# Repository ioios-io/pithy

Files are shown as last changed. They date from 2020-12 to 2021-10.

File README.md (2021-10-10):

# The Pithy Range @ [ioios.io](https://ioios.io/products/pithy)

     
---
## The quickest way to add extra control to your Smart Home
[](https://ioios.io) The Pithy range was conceived to fill the gap in the smart home arena so as to provide simple and intuitive phyiscal controls for adjusting volume, dimming lights, changing heating settings or whatever you chose!

The Open-Source devices are centered around a Wemos D1 Mini and they all feature a rotary encoder, a side switch and a temperature/huimdity sensor. Additionally, the Pixel model has a 16 LED NeoPixel ring for a display whilst the Screen model has... you guessed it, a screen.

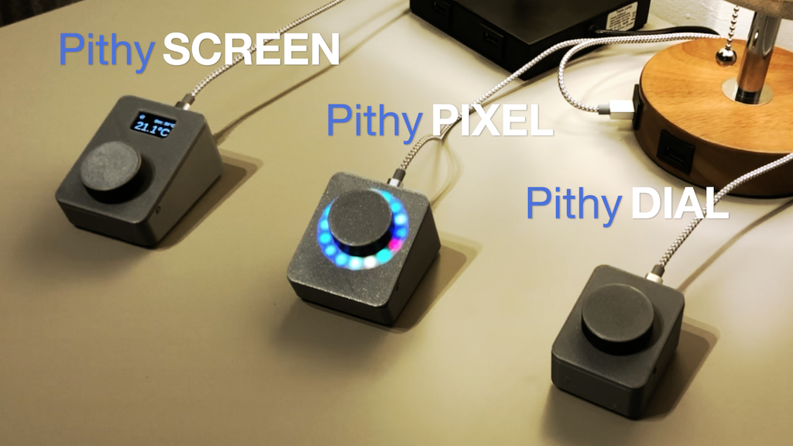
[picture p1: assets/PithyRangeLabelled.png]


## Pins
When writing esphome configuration for the Pithy range you will need to use the following pins for the latest board versions.

| Function | D1 Mini PIN |
|---|---|
| I2C Clock | D3 |
| I2C Data | D4 |
| Side Button | TX |
| PIR Sensor 1* | D1 |
| PIR Sensor 2* | D2 |
| Rotary Encoder A | D5 |
| Rotary Encoder B | D6 |
| Rotary Switch | D7 |
| NeoPixels* | RX |
| DHT22 Temp* | D0 |

(* Denotes items that may not be installed on all versions of a given model)

## The Files
In this repo you will find both the PCB files and the cases. In both sections the files are provided in multiple formats and include the official designs and also community contributions.
##### The Design Process
The PCBs were designed in Autodesk Eagle (using a custom made component library with 100% 3D renders). They were then imported/linked to Autodesk Fusion 360 where the cases were designed to perfectly fit and compliemnt the PCBs.
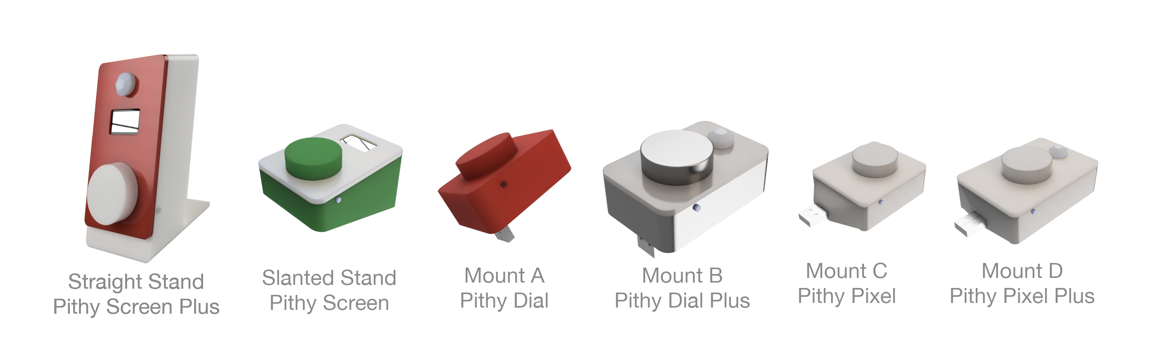
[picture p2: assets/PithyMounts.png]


## Contributions
It is Open-Source for a reason! If you would like to contribute your modifications or creations to the project, please follow these steps:
1. Fork this repo
2. Create a new, descriptively-named directory within the appropriate 'community' directory
3. Create a README.md file to briefly explain your ideas and if required, instructions for use/assembly
4. Don't forget to credit yourself and anyone else involved!
4. Create a pull request

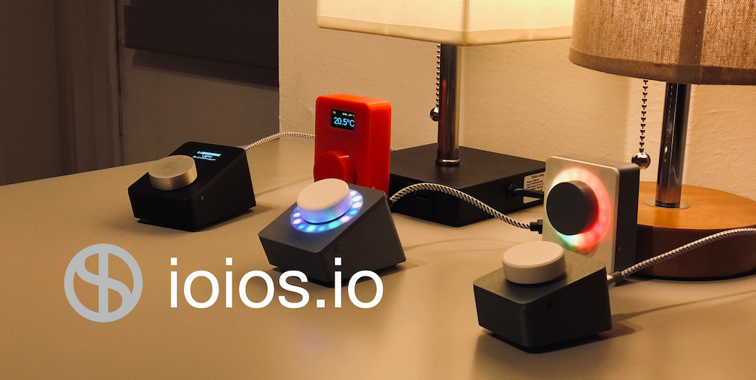
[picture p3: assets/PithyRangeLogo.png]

___

```
John Lumley
15th March 2021
```

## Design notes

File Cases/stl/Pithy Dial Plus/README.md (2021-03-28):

## Pithy Dial Plus
STL files for the Pithy Dial Plus models.
___

#### Mounting Options
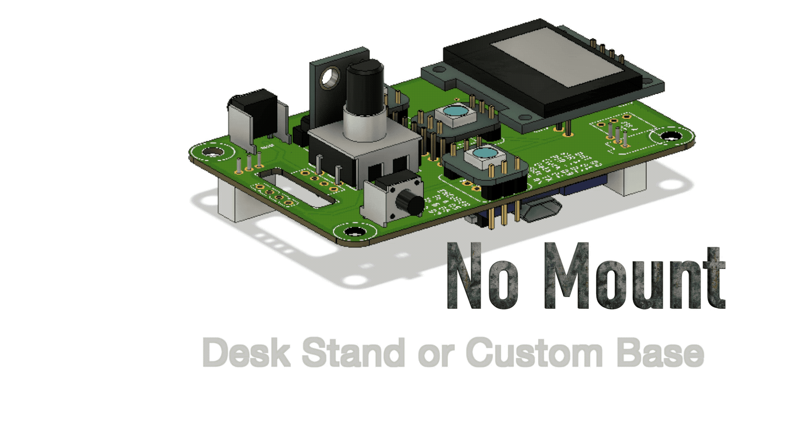
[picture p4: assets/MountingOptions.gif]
Mounting Options Animation


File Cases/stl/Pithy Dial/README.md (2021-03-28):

## Pithy Dial
STL files for the Pithy Dial models.
___

#### Mounting Options
Mounting Options Animation

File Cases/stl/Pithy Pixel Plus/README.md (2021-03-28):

## Pithy Pixel Plus
STL files for the Pithy Pixel Plus models.
___

#### Mounting Options
Mounting Options Animation

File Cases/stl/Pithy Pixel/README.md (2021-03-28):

## Pithy Pixel
STL files for the Pithy Pixel models.
___

#### Mounting Options
Mounting Options Animation

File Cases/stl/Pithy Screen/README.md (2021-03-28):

## Pithy Screen
STL files for the Pithy Screen models.
___

#### Mounting Options
Mounting Options Animation

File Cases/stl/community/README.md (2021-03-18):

# Community
## Entirely new configurations of Pithy PCBs
#### Ideally with full range of printable cases

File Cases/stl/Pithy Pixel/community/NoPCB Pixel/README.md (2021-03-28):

## Wemos D1 mini

I've added a case to use a standalone Wemos D1 mini without the PCB.

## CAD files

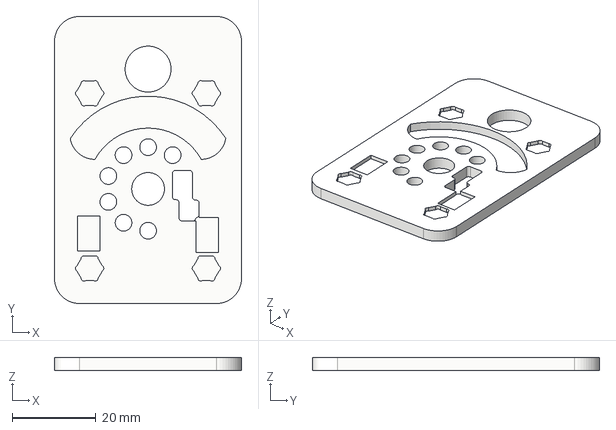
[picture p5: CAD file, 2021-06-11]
Cases/step/Pithy Dial Plus/Pithy Dial Plus Faceplate.step
44.8 x 68.7 x 3.00 mm

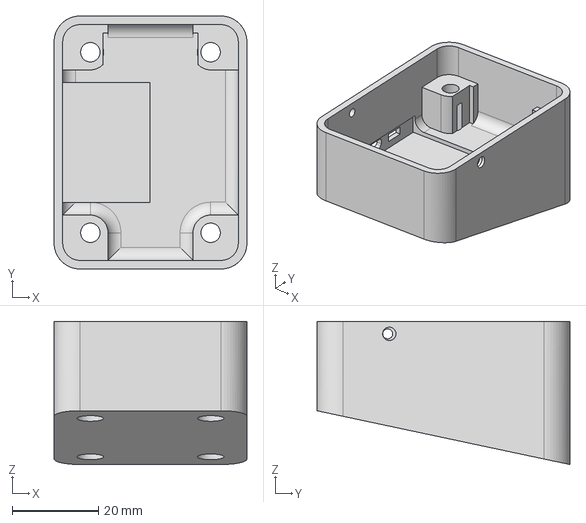
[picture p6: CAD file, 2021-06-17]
Cases/step/Pithy Dial/Pithy Dial Slanted Stand.step
44.8 x 58.7 x 33.2 mm

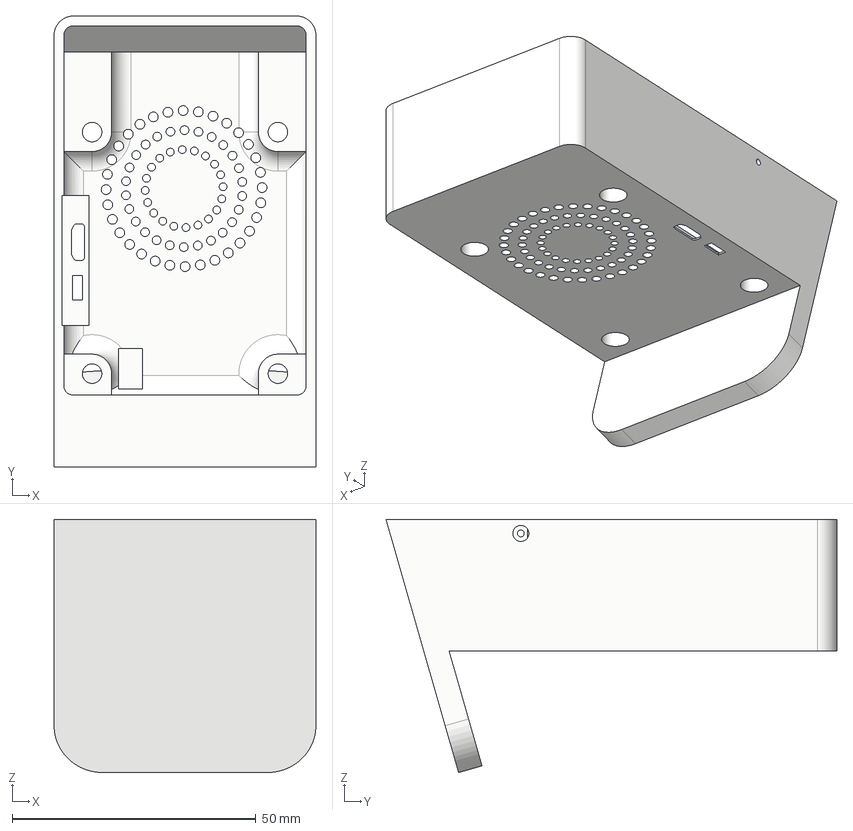
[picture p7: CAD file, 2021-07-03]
Cases/step/Pithy Pixel Plus/Pithy Pixel Plus Straight Stand.step
53.7 x 92.5 x 51.9 mm

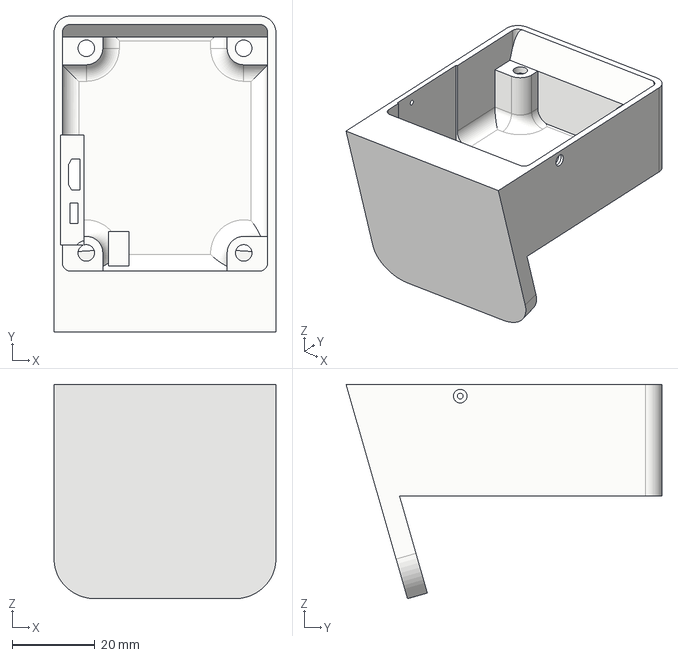
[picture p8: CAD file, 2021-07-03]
Cases/step/Pithy Pixel/Pithy Pixel Straight Stand.step
53.7 x 76.5 x 51.9 mm

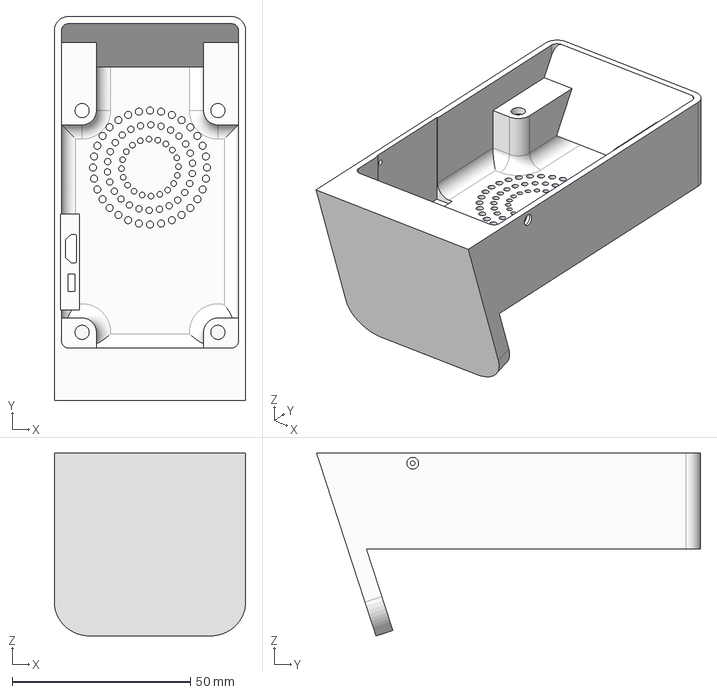
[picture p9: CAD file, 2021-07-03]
Cases/step/Pithy Screen Plus/Pithy Screen Plus Straight Stand.step
53.7 x 107.8 x 51.4 mm

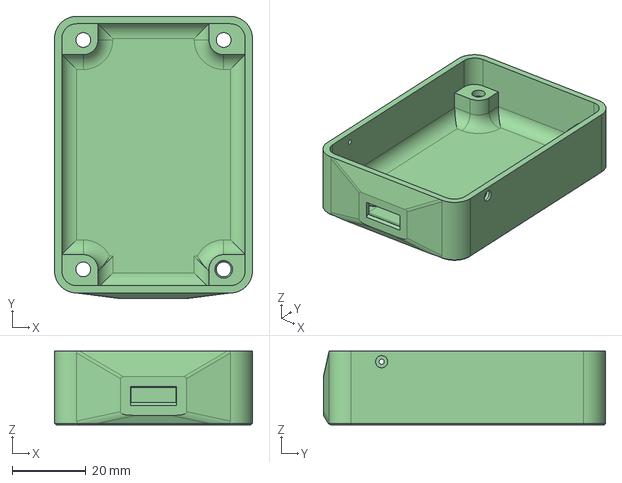
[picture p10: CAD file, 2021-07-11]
Cases/step/Pithy Screen/Pithy Screen Mount D.step
53.7 x 76.6 x 20.0 mm

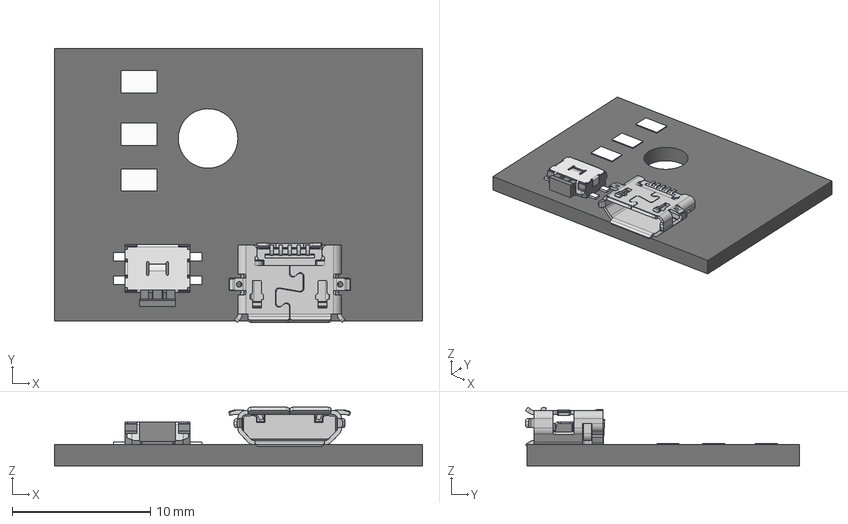
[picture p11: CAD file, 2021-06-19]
Cases/step/USB Micro Adapter.step
26.6 x 19.8 x 4.23 mm
zx62r-b-5p_30_
frame
pins
pins (1)
pins (2)
pins (3)
stem
cover
PCB

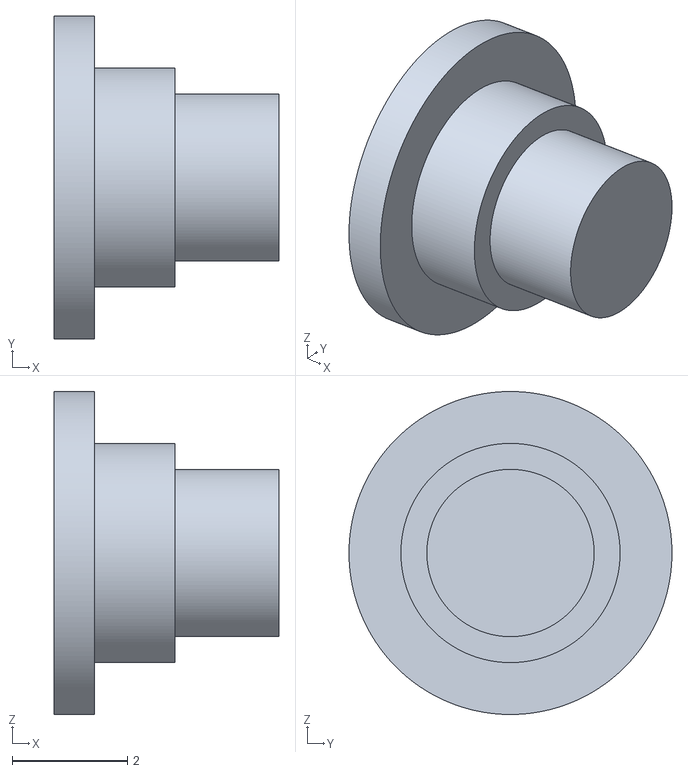
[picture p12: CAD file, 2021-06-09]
Cases/stl/Pithy Dial Plus/Pithy Secret Switch.stl
3.90 x 5.60 x 5.60

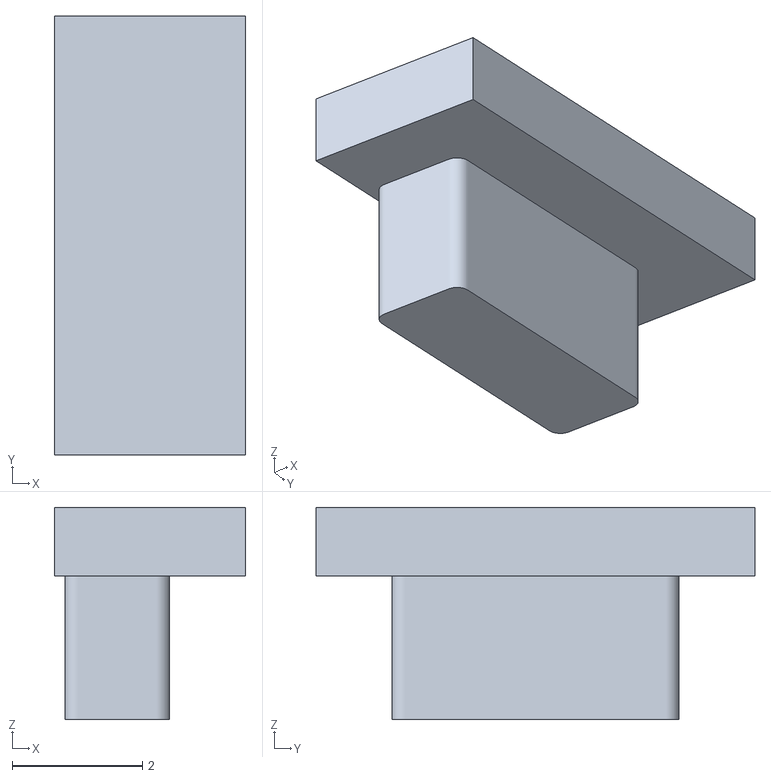
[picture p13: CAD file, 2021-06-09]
Cases/stl/Pithy Pixel Plus/Pithy Reset Switch.stl
2.93 x 6.73 x 3.25

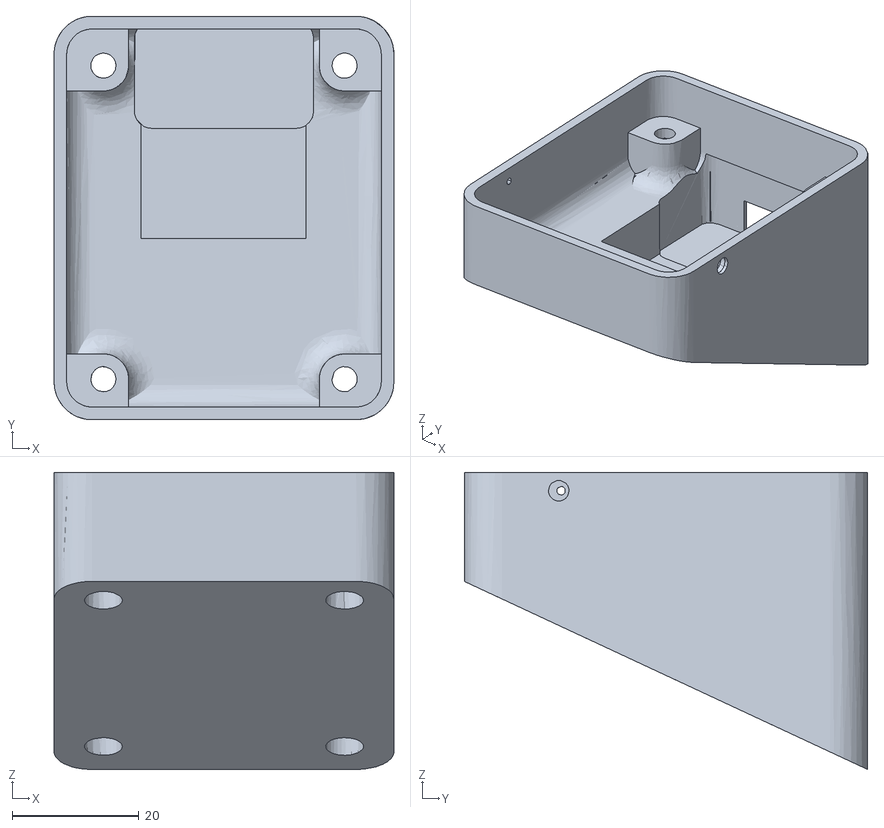
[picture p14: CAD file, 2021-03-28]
Cases/stl/Pithy Pixel/community/NoPCB Pixel/NoPCB Pixel.stl
53.7 x 63.8 x 46.9

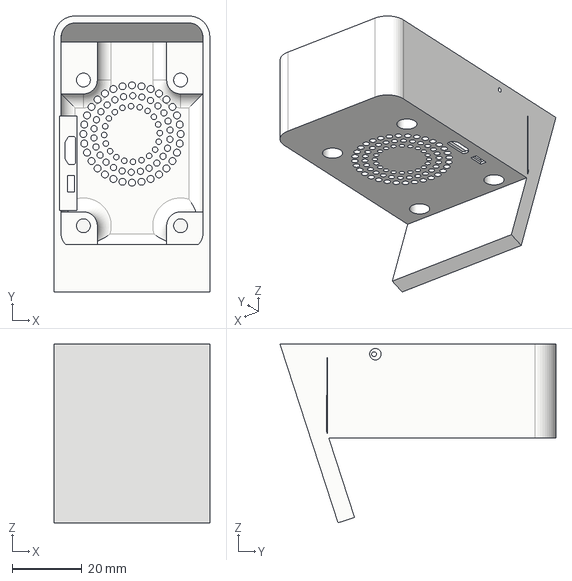
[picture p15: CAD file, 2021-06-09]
Cases/step/Pithy Dial Plus/Pithy Dial Plus Straight Stand.step
44.8 x 79.4 x 51.4 mm

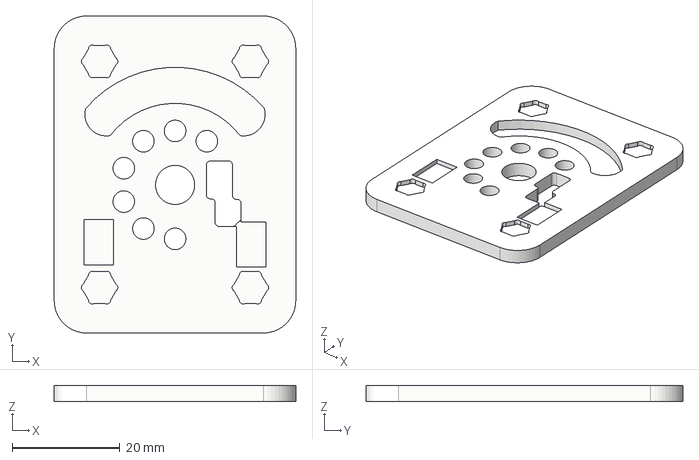
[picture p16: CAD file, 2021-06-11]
Cases/step/Pithy Dial/Pithy Dial Faceplate.step
44.8 x 58.7 x 3.00 mm

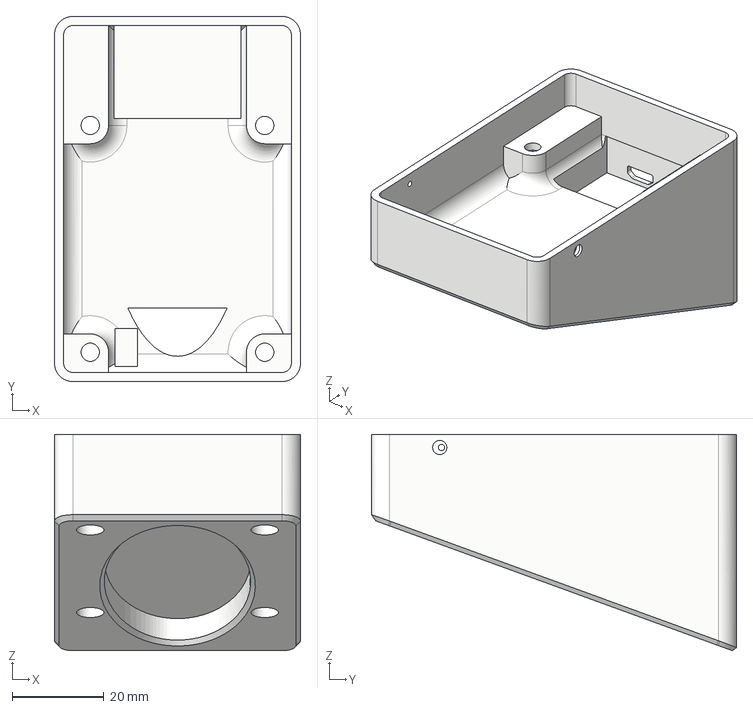
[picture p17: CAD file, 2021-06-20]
Cases/step/Pithy Pixel Plus/Pithy Pixel Plus Slanted Stand.step
53.7 x 79.8 x 47.2 mm

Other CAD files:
Cases/step/Pithy Pixel/Pithy Pixel Slanted Stand.step
Cases/step/Pithy Dial Multi Mount.step
Cases/step/Pithy Dial Plus/Pithy Dial Plus Mount A.step
Cases/step/Pithy Dial Plus/Pithy Dial Plus Mount B.step
Cases/step/Pithy Dial Plus/Pithy Dial Plus Mount C.step
Cases/step/Pithy Dial Plus/Pithy Dial Plus Mount D.step
Cases/step/Pithy Dial/Pithy Dial Mount A.step
Cases/step/Pithy Dial/Pithy Dial Mount B.step
Cases/step/Pithy Dial/Pithy Dial Mount C.step
Cases/step/Pithy Dial/Pithy Dial Mount D.step
Cases/step/Pithy PIxel Multi Mount.step
Cases/step/Pithy Pixel Plus/Pithy Pixel Plus Faceplate.step
Cases/step/Pithy Pixel Plus/Pithy Pixel Plus Mount A.step
Cases/step/Pithy Pixel Plus/Pithy Pixel Plus Mount B.step
Cases/step/Pithy Pixel Plus/Pithy Pixel Plus Mount C.step
Cases/step/Pithy Pixel Plus/Pithy Pixel Plus Mount D.step
Cases/step/Pithy Pixel/Pithy Pixel Faceplate.step
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

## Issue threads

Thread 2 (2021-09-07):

Pithy screen plus stuck on loading screen

Adam-North, 2021-09-07:
just flashed the d1 mini and it boots up correctly when plugged in directly to the d1 mini but not when plugged in through the power board. The loading bar just scrolls across the screen.

Adam-North, 2021-09-07:
pir sensor was preventing bootup. resoldered it and it works now.

Closed 2021-09-07.

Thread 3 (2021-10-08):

Pin numbers & PDF of the wiring diagram

mikeyyuen, 2021-10-08:
Hello, would you mind putting a specification for what the different pins people should use in the esphome files?

e.g. https://github.com/ioios-io/demos/blob/main/Home%20Assistant%20with%20ESPHome/4.%20All-In-One/All-In-One-ESPHome-PithyScreen.yaml

I've noticed some of the examples in the demo folder use D1/2 for i2c and others use D3/4, I wondered if it might be different for different models, but I have a pith screen plus and couldn't get most of the demo's to work out of the box.

ioios-io, 2021-10-10:
Hi Mike,
Yes, I'll add that to the to-do list but can't promise when it'll hit Github. I appreciate it is useful information (the pins are on the front of the PCB but pre-built units will never see those).

In the meantime, here is a list of the pin mappings at least.

D0: DHT
D1: PIR 1
D2: PIR 2
D3: I2C Clock
D4: I2C Data
D5: Encoder 1
D6: Encoder 2
D7: Encoder Switch
TX: Side Switch
RX: Neopixels

Thanks,
John

mikeyyuen, 2021-10-10:
Thank you, and your welcome for the pr! Glad I could help a little bit!

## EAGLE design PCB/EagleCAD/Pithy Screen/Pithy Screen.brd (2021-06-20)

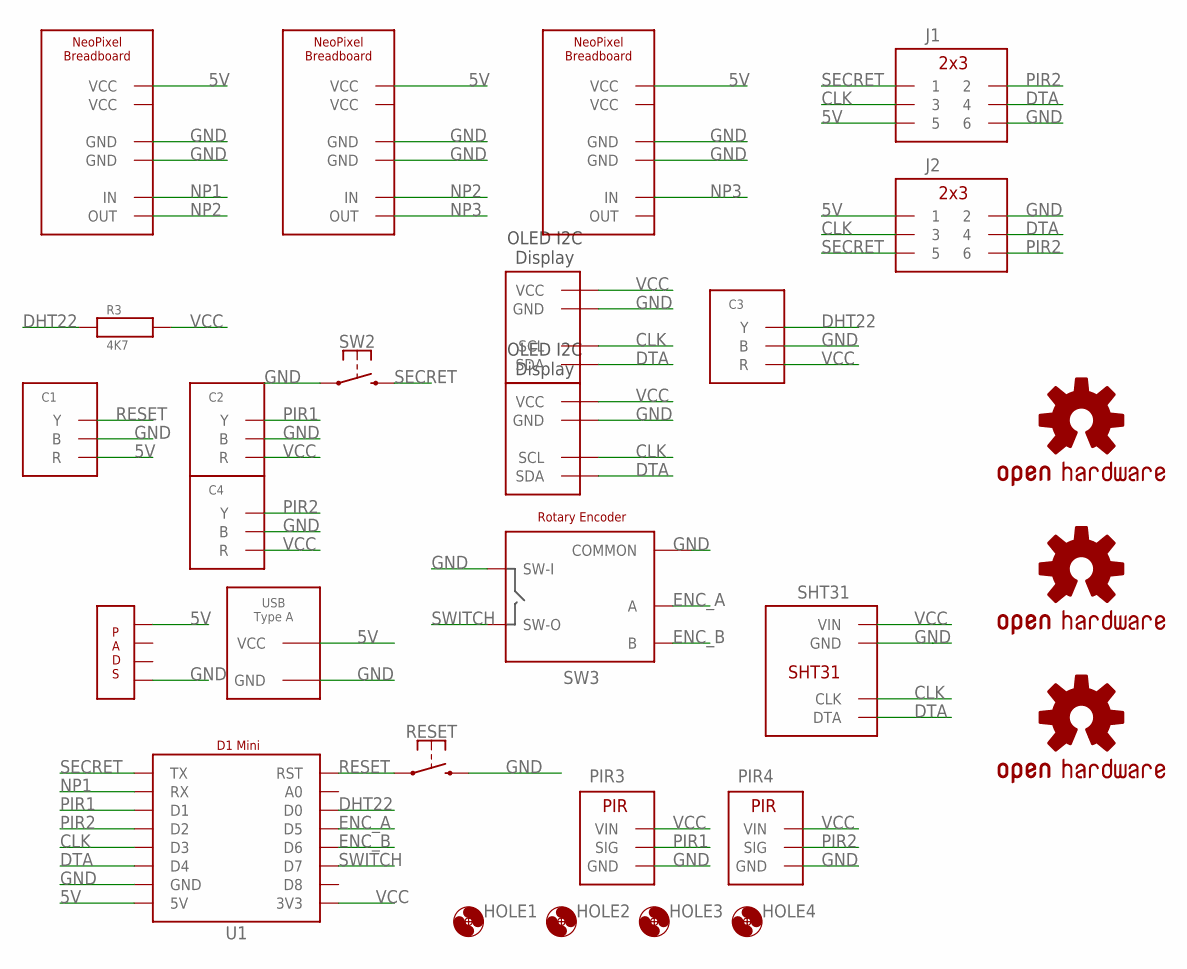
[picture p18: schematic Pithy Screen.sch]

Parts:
C1, C2, C3, C4: JST_2MM_3PIN
HOLE1, HOLE2, HOLE3, HOLE4: HOLE_3.2
J1, J2: DIL_2X03FEMALE; 2X3-RAF
LOGO1: OSHW-LOGOL; OSHW-LOGO-L
LOGO2: OSHW-LOGOM; OSHW-LOGO-M
LOGO3: OSHW-LOGOS; OSHW-LOGO-S
NP1, NP2, NP3: NEOPIXEL_BREADBOARD
PIR3, PIR4: PIR45DEG; PIR_45DEG
R3: 4K7; 1/4W_RESISTOR
RESET: SPDT_MOMENTARY; SPDT_RIGHT_ANGLE
SHT31: SHT31RIGHT_ANGLED; SHT31_RIGHT_ANGLE
SW2: SPDT_MOMENTARY; SPDT_RIGHT_ANGLE
SW3: ENCODER; ROTARY_ENCODER
U1: D1_MINI
U2, U3: OLED_I2C_0.9"VCC_LEFT; OLED_I2C_0.9"_ALT
U$1: USB_TYPE_A; USB_TYPE_A_BACKWARDS
U$2: PADS_4

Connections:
5V: C1.RED (R), J1.5, J2.1, NP1.VCC, NP2.VCC, NP3.VCC, U1.5V, U$1.VCC, U$2.P$4
CLK: J1.3, J2.3, SHT31.CLK, U1.D3, U2.SCL, U3.SCL
DHT22: C3.YELLOW (Y), R3.P$1, U1.D0
DTA: J1.4, J2.4, SHT31.DTA, U1.D4, U2.SDA, U3.SDA
ENC_A: SW3.A, U1.D5
ENC_B: SW3.B, U1.D6
GND: C1.BLACK (B), C2.BLACK (B), C3.BLACK (B), C4.BLACK (B), J1.6, J2.2, NP1.GND, NP1.GND@2 (GND), NP2.GND, NP2.GND@2 (GND), NP3.GND, NP3.GND@2 (GND), PIR3.GND, PIR4.GND, RESET.2 (3), SHT31.GND, SW2.1, SW3.C (COMMON), SW3.SW+ (SW-I), U1.GND, U2.GND, U3.GND, U$1.GND, U$2.P$1
NP1: NP1.IN, U1.RX
NP2: NP1.OUT, NP2.IN
NP3: NP2.OUT, NP3.IN
PIR1: C2.YELLOW (Y), PIR3.SIG, U1.D1
PIR2: C4.YELLOW (Y), J1.2, J2.6, PIR4.SIG, U1.D2
RESET: C1.YELLOW (Y), RESET.1, U1.RST
SECRET: J1.1, J2.5, SW2.2 (3), U1.TX
SWITCH: SW3.SW- (SW-O), U1.D7
VCC: C2.RED (R), C3.RED (R), C4.RED (R), PIR3.VCC (VIN), PIR4.VCC (VIN), R3.P$2, SHT31.VIN, U1.3V3, U2.VCC, U3.VCC

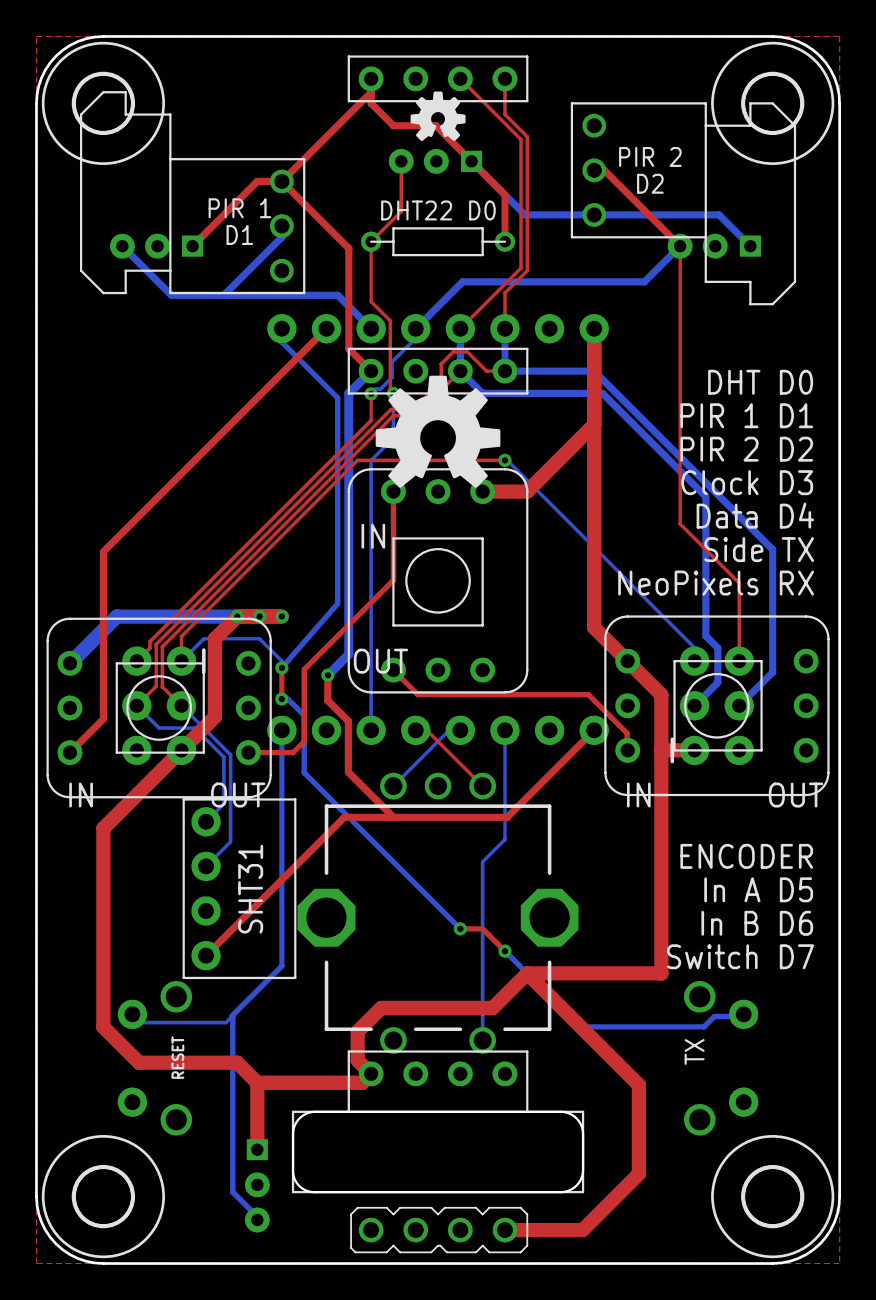
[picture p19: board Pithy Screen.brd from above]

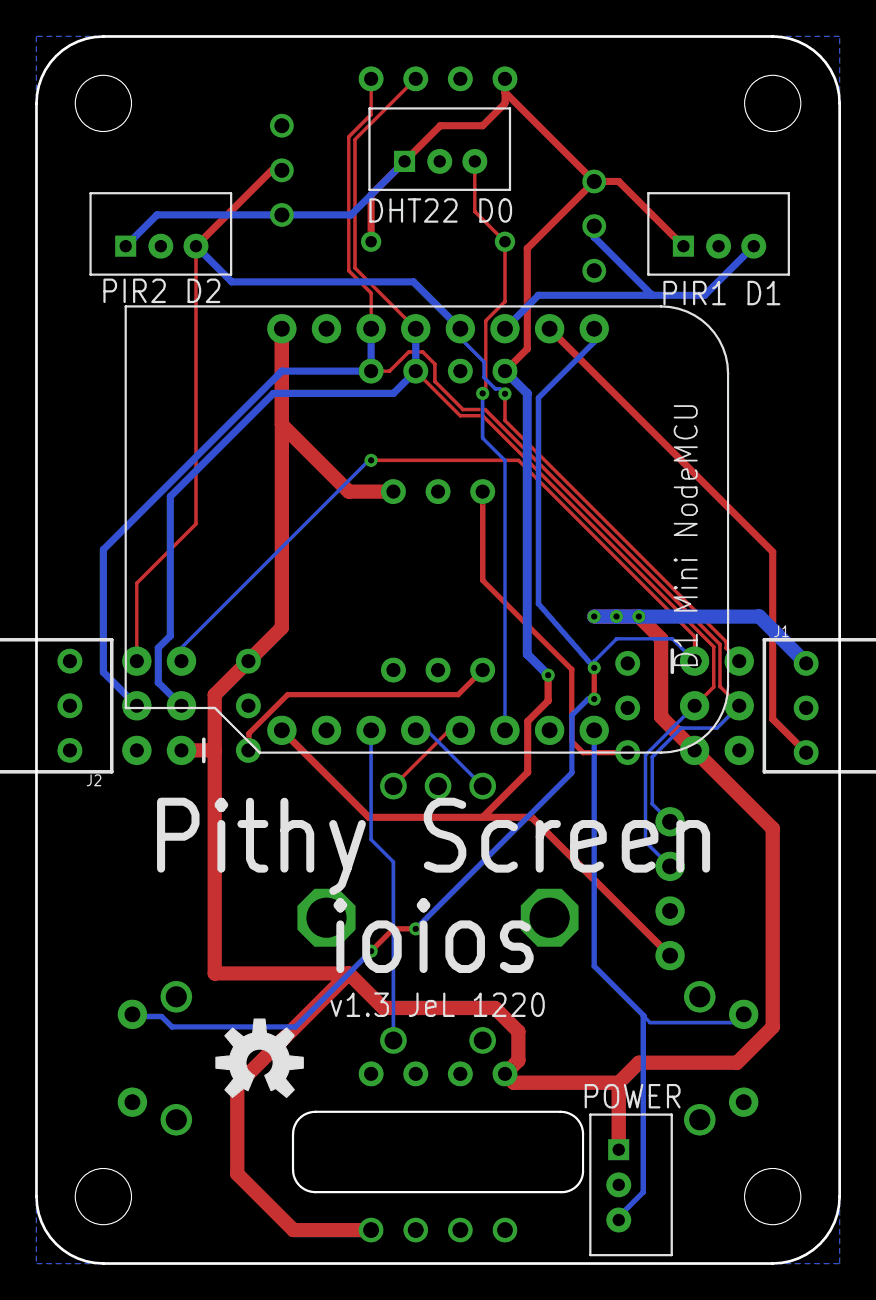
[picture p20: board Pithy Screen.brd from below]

Board: 2 copper layers, 45.7 x 69.8 mm, 28 parts (8 on the bottom side), 16 nets.

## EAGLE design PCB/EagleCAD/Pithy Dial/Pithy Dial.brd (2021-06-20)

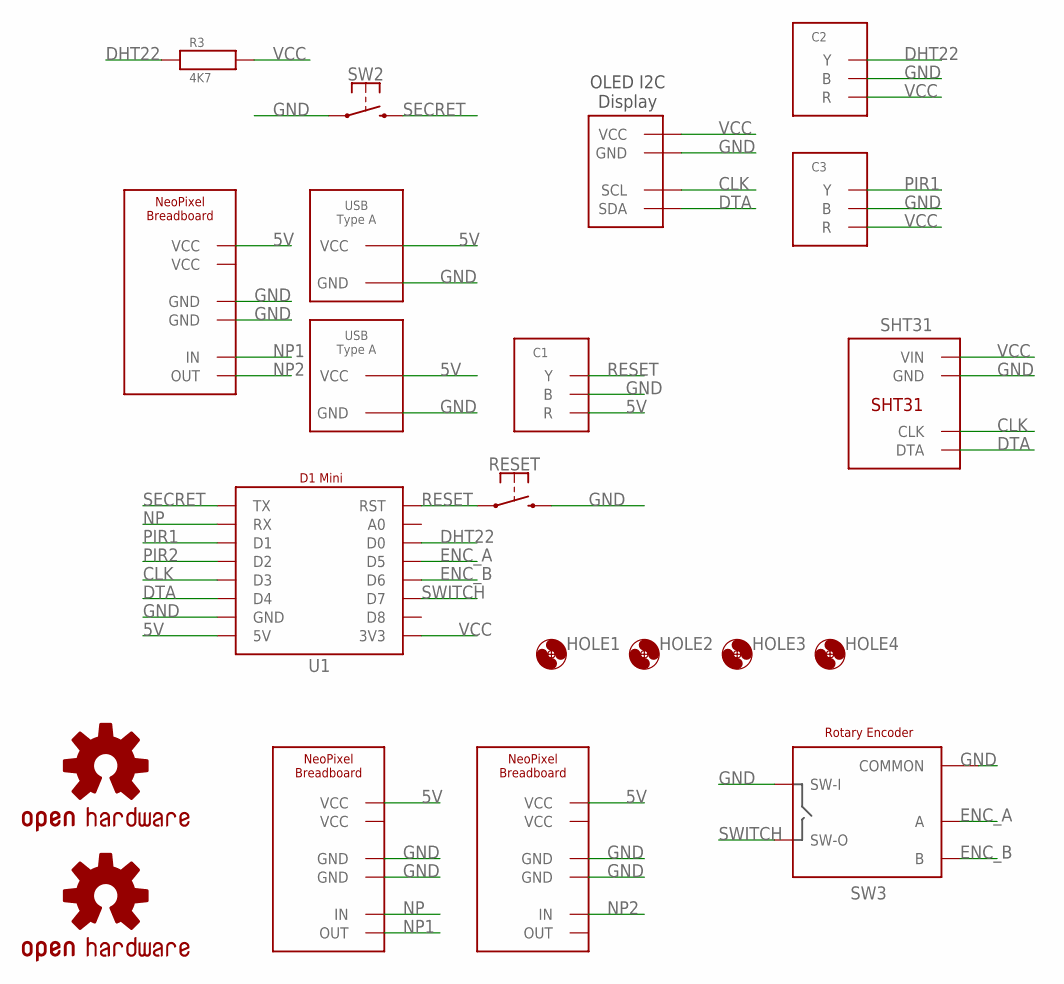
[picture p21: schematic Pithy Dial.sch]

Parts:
C1, C2, C3: JST_2MM_3PIN
HOLE1, HOLE2, HOLE3, HOLE4: HOLE_3.2
LOGO1: OSHW-LOGOM; OSHW-LOGO-M
LOGO2: OSHW-LOGOS; OSHW-LOGO-S
NP1: NEOPIXEL_BREADBOARD
NP2: LEFT_NEOPIXEL; NEOPIXEL_BREADBOARD
NP3: RIGHT_NEOPIXEL; NEOPIXEL_BREADBOARD
R3: 4K7; 1/4W_RESISTOR
RESET: SPDT_MOMENTARY; SPDT_RIGHT_ANGLE
SHT31: SHT31RIGHT_ANGLED; SHT31_RIGHT_ANGLE
SW2: SPDT_MOMENTARY; SPDT_RIGHT_ANGLE
SW3: ENCODER; ROTARY_ENCODER
U1: D1_MINI
U2: OLED_I2C_0.9"VCC_LEFT; OLED_I2C_0.9"_ALT
U$1, U$3: USB_TYPE_A; USB_TYPE_A_BACKWARDS

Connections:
5V: C1.RED (R), NP1.VCC, NP2.VCC, NP3.VCC, U1.5V, U$1.VCC, U$3.VCC
CLK: SHT31.CLK, U1.D3, U2.SCL
DHT22: C2.YELLOW (Y), R3.P$1, U1.D0
DTA: SHT31.DTA, U1.D4, U2.SDA
ENC_A: SW3.A, U1.D5
ENC_B: SW3.B, U1.D6
GND: C1.BLACK (B), C2.BLACK (B), C3.BLACK (B), NP1.GND, NP1.GND@2 (GND), NP2.GND, NP2.GND@2 (GND), NP3.GND, NP3.GND@2 (GND), RESET.2 (3), SHT31.GND, SW2.1, SW3.C (COMMON), SW3.SW+ (SW-I), U1.GND, U2.GND, U$1.GND, U$3.GND
NP: NP2.IN, U1.RX
NP1: NP1.IN, NP2.OUT
NP2: NP1.OUT, NP3.IN
PIR1: C3.YELLOW (Y), U1.D1
PIR2: U1.D2
RESET: C1.YELLOW (Y), RESET.1, U1.RST
SECRET: SW2.2 (3), U1.TX
SWITCH: SW3.SW- (SW-O), U1.D7
VCC: C2.RED (R), C3.RED (R), R3.P$2, SHT31.VIN, U1.3V3, U2.VCC

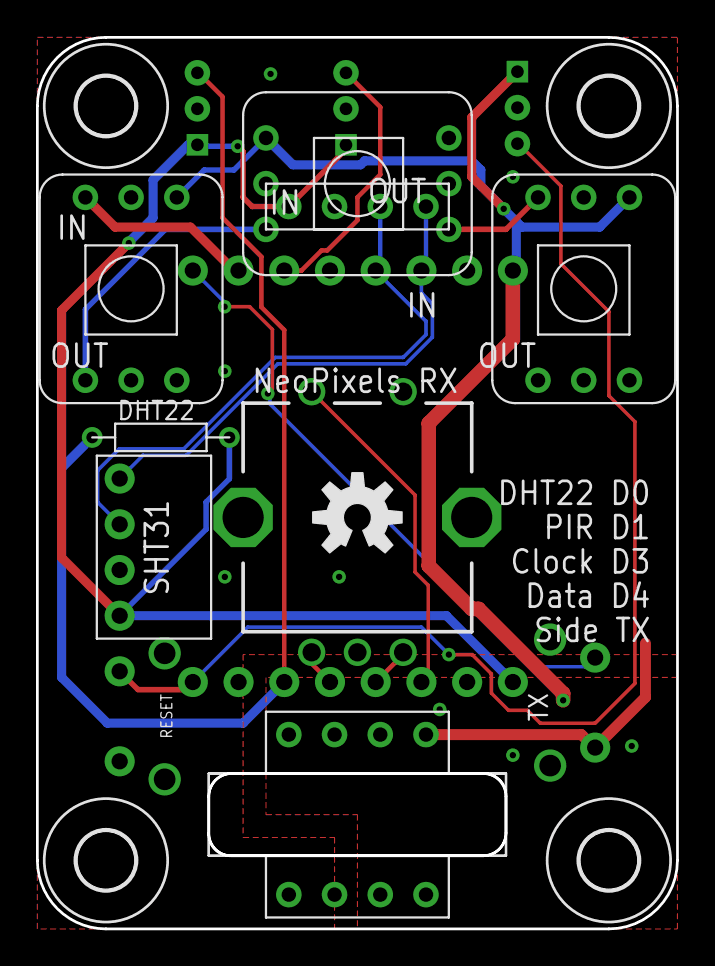
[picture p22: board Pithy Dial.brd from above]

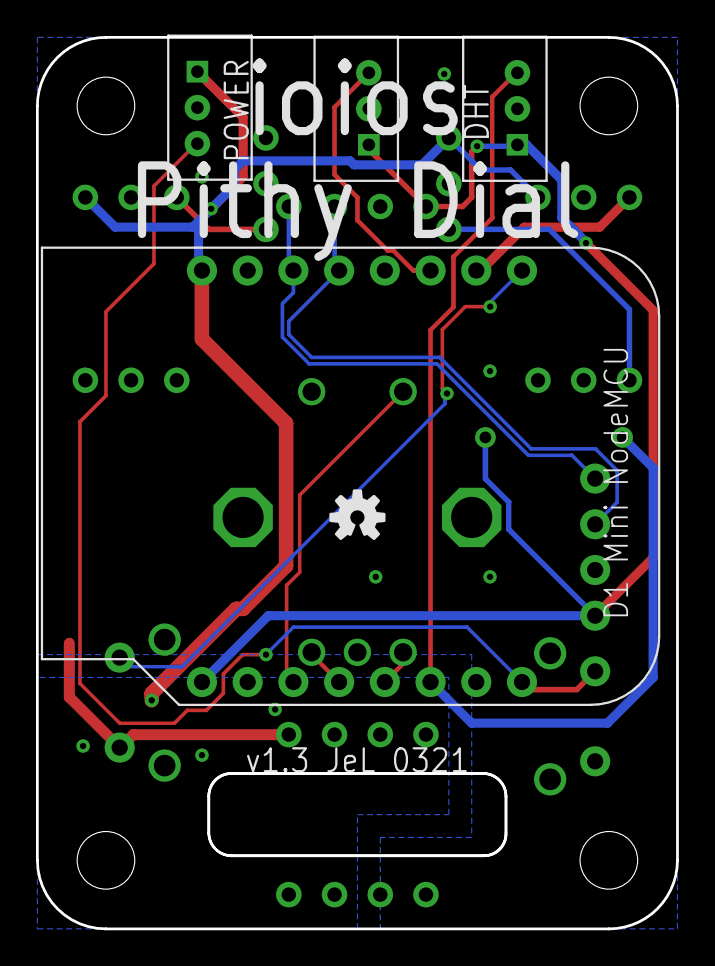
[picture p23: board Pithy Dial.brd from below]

Board: 2 copper layers, 35.6 x 49.5 mm, 21 parts (5 on the bottom side), 15 nets.

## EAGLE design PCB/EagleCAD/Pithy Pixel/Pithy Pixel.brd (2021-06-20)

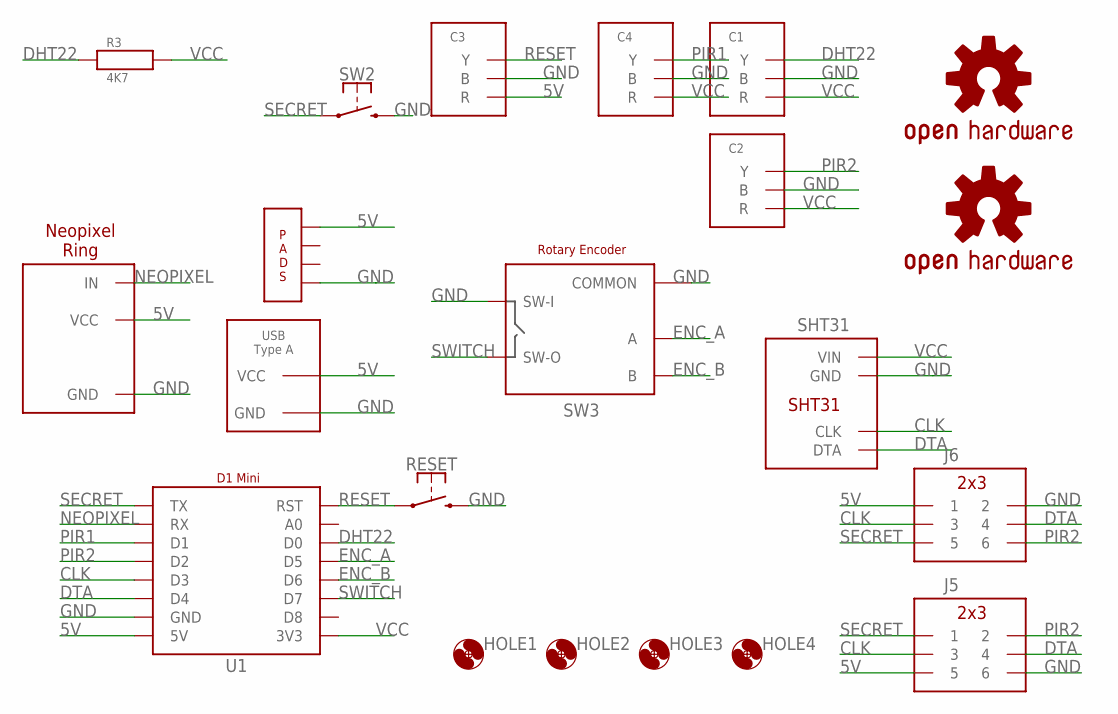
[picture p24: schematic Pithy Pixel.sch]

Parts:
C1, C2, C3, C4: JST_2MM_3PIN
HOLE1, HOLE2, HOLE3, HOLE4: HOLE_3.2
IC1: NEOPIXEL_RING_NO_OUT; NEOPIXEL_RING_SMALL_NO_OUT
J5, J6: DIL_2X03FEMALE; 2X3-RAF
LOGO1: OSHW-LOGOM; OSHW-LOGO-M
LOGO2: OSHW-LOGOS; OSHW-LOGO-S
R3: 4K7; 1/4W_RESISTOR
RESET: SPDT_MOMENTARY; SPDT_RIGHT_ANGLE
SHT31: SHT31RIGHT_ANGLED; SHT31_RIGHT_ANGLE
SW2: SPDT_MOMENTARY; SPDT_RIGHT_ANGLE
SW3: ENCODER; ROTARY_ENCODER
U1: D1_MINI
U$1: USB_TYPE_A; USB_TYPE_A_BACKWARDS
U$2: PADS_4

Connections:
5V: C3.RED (R), IC1.VCC@1 (VCC), J5.5, J6.1, U1.5V, U$1.VCC, U$2.P$4
CLK: J5.3, J6.3, SHT31.CLK, U1.D3
DHT22: C1.YELLOW (Y), R3.P$1, U1.D0
DTA: J5.4, J6.4, SHT31.DTA, U1.D4
ENC_A: SW3.A, U1.D5
ENC_B: SW3.B, U1.D6
GND: C1.BLACK (B), C2.BLACK (B), C3.BLACK (B), C4.BLACK (B), IC1.GND@2 (GND), J5.6, J6.2, RESET.2 (3), SHT31.GND, SW2.2 (3), SW3.C (COMMON), SW3.SW+ (SW-I), U1.GND, U$1.GND, U$2.P$1
NEOPIXEL: IC1.IN, U1.RX
PIR1: C4.YELLOW (Y), U1.D1
PIR2: C2.YELLOW (Y), J5.2, J6.6, U1.D2
RESET: C3.YELLOW (Y), RESET.1, U1.RST
SECRET: J5.1, J6.5, SW2.1, U1.TX
SWITCH: SW3.SW- (SW-O), U1.D7
VCC: C1.RED (R), C2.RED (R), C4.RED (R), R3.P$2, SHT31.VIN, U1.3V3

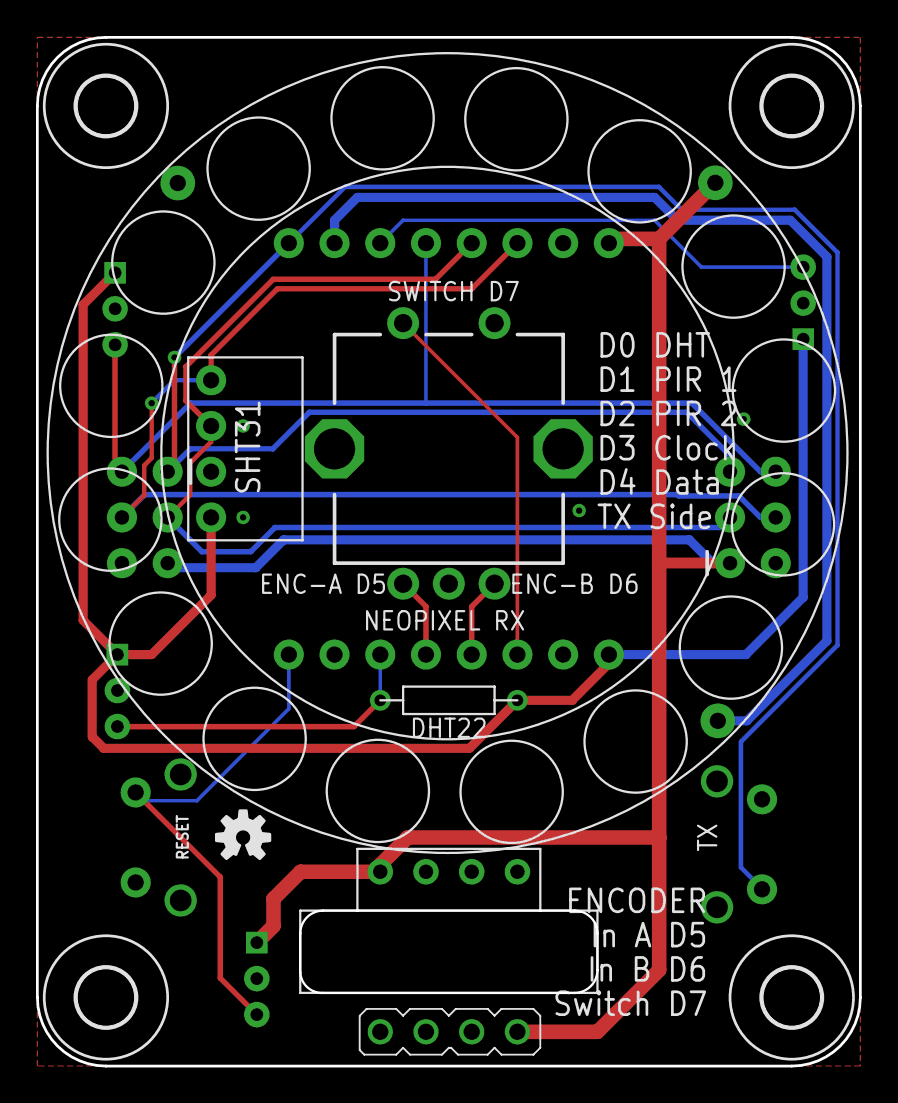
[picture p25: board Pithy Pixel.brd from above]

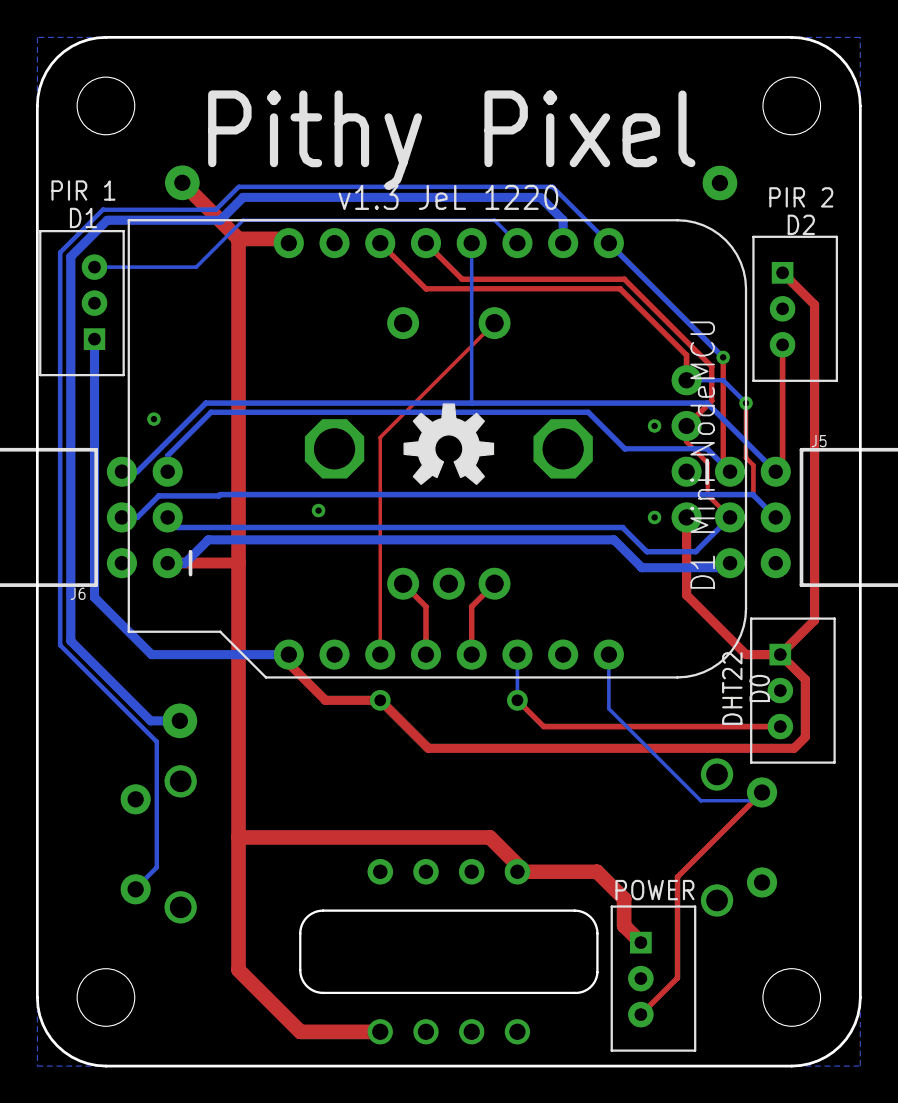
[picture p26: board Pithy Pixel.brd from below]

Board: 2 copper layers, 45.7 x 57.1 mm, 21 parts (8 on the bottom side), 14 nets.

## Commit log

2020-12-08 Added first STL files
    [Pithy Screen Base.stl, Pithy Screen Faceplate.stl, Pithy Screen Plus Base.stl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]
2020-12-21 Adding Pithy Screen Plus range
    [Pithy Screen Plus Base.stl, Pithy Screen Plus Desktop Stand.stl, Pithy Screen Plus Faceplate.stl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]
2021-02-01 Screen and Screen Plus stp files
    [Pithy Screen Faceplate.step, Pithy Screen Mount A.step, Pithy Screen Mount B.step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]
2021-02-05 Adding Screen STLs
    [Pithy Screen Base.stl, Pithy Screen Faceplate.stl, Pithy Screen Mount A.stl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]
2021-02-05 Adding Pixel STLs
    [Pithy Pixel Faceplate.stl, Pithy Pixel Mount A.stl, Pithy Pixel Mount B.stl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]
2021-02-10 Screen Plus Faceplate updates
    [Pithy Screen Plus Faceplate.stl]
2021-03-18 Pithy Dial Plus basics
    [Pithy Dial Plus Faceplate.stl, Pithy Dial Plus Mount A.stl, Printed Knob Standard.stl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]
2021-03-18 Pithy Dialbasics
    [Pithy Dial Faceplate.stl, Pithy Dial Mount A.stl, Printed Knob Standard.stl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]
2021-03-18 Pithy Pixel Plus basics
    [Pithy Pixel Plus Faceplate.stl, Pithy Pixel Plus Mount A.stl, Printed Knob Standard.stl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]
2021-03-18 Added Wemos STL
    [Pithy Pixel Wemos D1 mini.stl]
2021-03-18 Thickening base
    [Pithy Dial Mount A.stl, Pithy Dial Plus Mount A.stl]
2021-03-18 move files to new community folder
    [Pithy Pixel Wemos D1 mini.stl]
2021-03-18 Directory & file rename
    [NoPCB Pixel.stl]
2021-03-28 Bulk upload of STLs
    [Pithy Dial Faceplate.stl, Pithy Dial Mount A.stl, Pithy Dial Mount B.stl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]
2021-03-28 Bulk upload of STEPs
    [Pithy Dial Faceplate.step, Pithy Dial Mount A.step, Pithy Dial Mount B.step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]
2021-04-07 Adding mount options image
2021-06-05 Updating slanted stands
    [Pithy Pixel Plus Faceplate.step, Pithy Pixel Plus Faceplate.stl, Pithy Pixel Slanted Stand.stl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]
2021-06-09 Adding stls
    [Pithy Dial Plus Straight Stand.stl, Pithy Dial Slanted Stand.stl, Pithy Pixel Plus Straight Stand.stl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]
2021-06-09 Adding steps
    [Pithy Dial Plus Straight Stand.step, Pithy Dial Slanted Stand.step, Pithy Pixel Plus Straight Stand.step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]
2021-06-19 Updating desk stands
    [Pithy Pixel Plus Slanted Stand.step, Pithy Pixel Plus Straight Stand.step, Pithy Pixel Slanted Stand.step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]
2021-06-20 Adding PCB Files
    [Pithy Dial.brd, Pithy Dial.sch, Pithy Pixel.brd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]
2021-06-21 Adding Screen Straight Stand stl
    [Pithy Screen Straight Stand.stl]
2021-06-21 Adding Screen Straight Stand step
    [Pithy Screen Straight Stand.step]
2021-07-03 Modifying straight stands
    [Pithy Pixel Plus Straight Stand.stl, Pithy Pixel Straight Stand.stl, Pithy Screen Plus Straight Stand.stl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]
2021-07-11 Pithy Screen Updates
    [Pithy Screen Mount A.step, Pithy Screen Mount C.step, Pithy Screen Mount D.step]
2021-10-08 Document the pin outs
    Partially addresses #3, adds a table documenting the pinouts for the D1 mini and which components they connect to.
